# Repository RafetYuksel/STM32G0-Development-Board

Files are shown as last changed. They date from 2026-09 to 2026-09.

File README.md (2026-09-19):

# STM32G0-Development-Board

A custom 4-layer development board based on the **STM32G0B1RET6** microcontroller, designed from schematic through PCB layout with a focus on practical hardware design, power management, USB, industrial communication interfaces, debugging, and PCB design practices.

---

## Overview

This project is a custom STM32G0 development board designed and developed from the ground up.

The board provides a general-purpose hardware platform for embedded development and includes USB connectivity, CAN, RS485, SWD debugging, UART, I2C and SPI interfaces.

The design process includes:

- System architecture
- Schematic design
- Component selection
- Power architecture
- PCB layout
- 4-layer PCB stack-up
- Ground-plane design
- USB differential-pair routing
- Communication interfaces
- Design Rule Check (DRC) 
- PCB manufacturing
- Hardware bring-up

---

## Key Features

| Feature | Description |
|---|---|
| MCU | STM32G0B1RET6 |
| PCB | 4-layer |
| USB | USB Type-C |
| Debug | SWD |
| CAN | FDCAN1 |
| RS485 | MAX3485 |
| UART | USART2 |
| I2C | Header |
| SPI | Header |
| Logic Supply | 3.3 V |
| USB Supply | 5 V |
| External Input | Supported |
| Protection | Input protection and USB ESD protection |
| Status | LEDs and user button |

---

## System Architecture

```text
                         ┌─────────────────────┐
                         │      USB Type-C     │
                         │    Power + USB      │
                         └──────────┬──────────┘
                                    │
                                    ▼
                         ┌─────────────────────┐
                         │   Power Management  │
                         │ Protection + DC/DC  │
                         └──────────┬──────────┘
                                    │      
                              5 V / 3.3 V
                                    │
                                    ▼
                         ┌─────────────────────┐
                         │    STM32G0B1RET6    │
                         │        MCU          │
                         └──────┬──┬──┬──┬────┘
                                │  │  │  │
                    ┌───────────┘  │  │  └───────────┐
                    │              │  │              │
                    ▼              ▼  ▼              ▼
                  USB             CAN RS485       SWD
                    │              │  │              │
                    ▼              ▼  ▼              ▼
                USB ESD         Transceivers     Debugger
                Protection

```
---

## Hardware Design

### MCU
* **Main Controller:** STM32G0B1RET6
* Provides processing, communication, and peripheral interfaces required by the board.
* Includes local decoupling capacitors and dedicated filtering for the MCU supply.
* MCU analog supply is additionally filtered from the main 3.3 V rail.

### Power Management
Supports USB and external power input.

**Power Architecture:**
USB-C / External Input
          │
          ▼
   Input Protection
          │
          ▼
       SYS_5V
          │
          ▼
        3.3 V
          │
          ▼
    STM32G0 + Logic

### USB
USB connectivity is provided through a USB Type-C connector with data lines routed as a differential pair on the PCB.
* USB Type-C connector
* USB VBUS & CC resistors
* USB ESD protection
* USB differential data lines

### CAN
Connected to the STM32G0 FDCAN peripheral. The termination network allows configuration based on its position in the CAN bus.
* CANH / CANL lines
* CAN transceiver & connector
* Selectable termination (Jumper-selectable)

### RS485
Uses an MAX3485 transceiver for RS485 communication.
* MCU UART connection
* Driver Enable control
* RS485 A/B lines
* RS485 termination (Jumper-selectable)
* External connector

### Debug Interface
Provides Serial Wire Debug (SWD) interface for programming and debugging via an external ST-LINK debugger. Access provided to:
* SWDIO & SWCLK
* 3.3 V & GND
* MCU reset

### Peripheral Interfaces
Exposes several MCU peripherals through external headers to act as a general-purpose embedded development platform:
* UART, I2C, SPI
* CAN, RS485
* GPIO

---

## PCB Design

### Stack-up (4-Layer)
| Layer | Name | Description |
| :--- | :--- | :--- |
| **Layer 1** | TOP | Components and signal routing |
| **Layer 2** | GND | Ground plane |
| **Layer 3** | INNER SIGNAL | Signal routing |
| **Layer 4** | BOTTOM | Signal routing |

* A dedicated internal ground layer (Layer 2) provides continuous ground coverage, low-impedance return paths, and improved return-current dynamics.
* Ground stitching vias are placed throughout to enhance connections between ground regions.

### PCB Layout Considerations
* MCU decoupling capacitor placement & short USB signal paths
* Power-rail routing & ground-plane continuity
* USB differential-pair routing
* Communication-interface routing
* Ground stitching & signal/power routing
* **DRC:** Completed using CircuitMaker Design Rule Check.

---

## Design Decisions

* **4-Layer PCB:** Selected to provide additional routing space, low-impedance return paths, and a dedicated internal ground plane.
* **Ground Plane:** Dedicated GND plane on Layer 2 with stitching vias added where appropriate to improve continuity between PCB regions.
* **USB Differential Pair:** D+ and D− signals routed as a differential pair in a compact layout around the connector, ESD protection, and MCU.
* **Selectable CAN Termination:** Jumper-selectable termination resistor allows use at either end of a CAN bus or without local termination.
* **Selectable RS485 Termination:** Jumper-selectable termination network to enable or disable based on position in the network.

---

## Manufacturing & Status

### Manufacturing Workflow
Schematic -> PCB Layout -> DRC -> PCB Manufacturing -> Bare PCB Received -> Component Assembly -> Hardware Bring-up -> Firmware Validation

### Project Status
* **Hardware Design:** Complete
* **PCB Manufacturing:** Complete
* **Bare PCB:** Received
* **Component Assembly:** Pending
* **Hardware Bring-up:** Pending
* **Firmware Validation:** Pending

---

## Firmware & Bring-up Plan

Firmware development will be performed using **STM32CubeIDE**.

Planned firmware validation includes:
* GPIO, UART, USB, CAN, RS485
* ADC, Timers, PWM
* SWD debugging

### Hardware Bring-up Sequence
1. Visual inspection
2. Power-input verification
3. 5 V rail verification
4. 3.3 V rail verification
5. MCU supply verification
6. SWD connection
7. MCU programming
8. Peripheral tests (GPIO -> UART -> USB -> CAN -> RS485)

### Validation Matrix
| Function / Test | Status |
| :--- | :--- |
| Visual inspection | Pending |
| Power input | Pending |
| SYS_5V | Pending |
| 3.3 V | Pending |
| MCU power | Pending |
| SWD | Pending |
| GPIO | Pending |
| UART | Pending |
| USB | Pending |
| CAN | Pending |
| RS485 | Pending |

---

## Repository Structure

```text
STM32G0-Development-Board/
├── Hardware/
│   ├── Schematic/
│   ├── PCB/
│   ├── BOM/
│   └── 3D/
├── Firmware/
├── Documentation/
├── Images/
└── README.md

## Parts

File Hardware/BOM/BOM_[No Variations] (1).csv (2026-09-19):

Comment | Description | Designator | Footprint | LibRef | Quantity
C&K Components KSC421G70SHLFS | Switch Tactile N.O. SPST Round Button Gull Wing 0.05A 32VDC 1VA 300000Cycle 2.12N SMD T/R | BTN1 | PCBComponent_1 | CMP-7597bcf2a0aaaa50-3 | 1
10uF | Cap Ceramic 10uF 25V X5R 10% SMD 0805 85°C Embossed T/R | C1, C4 | PCB-p4p2p2gnhi9hwenucyw6-1 | CMP-5c4a946cea47838d-4 | 2
22uF | 0805 22uF 25V X5R 20% multilayer ceramic capacitor | C2, C5 | CAPC2013X94X50ML20T25 | CMP-ef25233f913230e2-1 | 2
100nF | Ceramic capacitor SMD-0603 100nF 50V X7R# K +-10%, Samsung, RoHS | C3, C6, C7, C9, C10, C11 | Samsung CL10B104KB8NNNC-Footprint-1 | CMP-1af8d38ac64bc53f-24 | 6
1uF | 1uF Ceramic capacitor SMD-0603 1uF 50V X5R# K +-10%, Samsung, RoHS | C8 | CAPC1608X90X35LL15T15 | CMP-f7023f64287128c5-7 | 1
4.7uF | Multilayer Ceramic Capacitors MLCC - SMD/SMT 0805 4.7uF 35volts X5R 20% | C12 | CAPC2013X95X45LL15T25 | CMP-8267229-2 | 1
100nF | Capacitor; ECWF, Met Polypropylene Film Cap, Radial, 50V, 10uF, 5%, Blk ST | C13, C14 | RESC2013X50X30ML20T20 | CMP-e7d62c864ecd3811-3 | 2
Fairchild Semiconductor SS14 | DIODE SCHOTTKY 40V 1A SMA | D1 | SMB | CMP-814764-5 | 1
VIN TVS | Diode; 30.2 A (Max.); 13.30 V (Min.) @ 1 mA; 5 uA (Max.) @ 12 V; 100 A (Max.) | D2 | PCB-9qq8yczch7qbe6np1bha-1 | CMP-f10c38c5a08b2ecb-7 | 1
OR-ing Schottky | PMEG4010AESB - 40 V, 1 A low VF MEGA Schottky barrier rectifier | D3 | Nexperia PMEG4010AESBYL-Footprint-1 | CMP-63ffae44396ebc38-2 | 1
Kingbright APFA3010SEKJ3ZGKQBKC | 3.0MMX1.0MM Right Angle SMD Chip Led Lamp | D4 | PCB-xa6wagpttn61v02uvygv-1 | CMP-91425c46545c4e85-2 | 1
GREEN | 2.4 V Green LED 1608 (0603) SMD, Lite-On LTST-C190KGKT | DS1 | LTST-C190KGKT | CMP-e1642866a00b3ea3-15 | 1
Bourns MF-PSMF050X-2 | FUSE PTC RESETTABLE SMD 0805 | F1 | PCB-277780-1 | CMP-277780-4 | 1
BLM18AG601SN1D | Chip Ferrite Bead for General Use, 600 Ohm, 500 mA, -55 to 125 degC, 1.6 x 0.8 x 0.95 mm SMD, Tape and Reel | FB1 | MURA-BLM18-RF-H4-CHIP-2_V | CMP-14419471-5 | 1
Samtec FTSH-105-01-F-DV-K | Conn Unshrouded Header HDR 10 POS 1.27mm Solder ST SMD Automotive Tube | J1 | PCB-sbymt8py0jvp2ryn5bcq-1 | CMP-51de9854a3aa8e19-9 | 1
TYPE-C-31-M-12 | 250mA 1 16 Female Type-C SMD USB Connectors ROHS | J2 | HRO Electronics TYPE-C-31-M-12-Footprint-1 | CMP-a3766f9095887cb1-3 | 1
TE Connectivity 825433-6 | Conn Unshrouded Header HDR 6 POS 2.54mm Solder ST Thru-Hole - No Outline | J5 | PCB-2xrknp0frdgvb29ud8aa-1 | CMP-88ed4362af17572a-9 | 1
Harwin M50-3530242 | Prices include import duty and tax. BTB CONN, HEADER, 2POS, 1ROWS, 1.27MM | J6, J7 | PCB-kdbzezog7lgzeuckpa59-1 | CMP-8a7247a62d3655b5-1 | 2
Molex 0022284100 | 2.54mm (.100") Pitch KK® Header, Breakaway, Vertical, 10 Circuits, Tin (Sn) Plating, Mating Pin Length 6.09mm (.240") | J8 | HDR1X10 | CMP-4d308488f3b592f7-3 | 1
Samtec TSM-112-01-L-SV | "This surface mount .025” square post terminal strip features single | J9 | Samtec TSM-112-01-L-SV-Footprint-1 | CMP-86a14eaf92625966-1 | 1
Phoenix Contact 1729128 | SERVAL Bornera negra 2 vias | J_EXT | PCB-751788-1 | CMP-751788-39 | 1
Amphenol ICC / FCI 68000-103HLF | Conn Unshrouded Header HDR 3 POS 2.54mm Solder ST Top Entry Thru-Hole BergStik® Bulk | JP1, JP2 | Hdr_1x3_2.54mm | CMP-8ffa44933221503d-6 | 2
Coilcraft XAL5030-472MEC | Power inductor, shielded, 20% tol, SMT, RoHS, halogen f | L1, L2 | PCB-eh2uh0b1ckxc83nsi4qq-1 | CMP-6f03a7253721b0c4-1 | 2
P-MOSFET | Power MOSFET, -20 V, -1 A, P-Channel, 3-Pin SOT-23, Pb-Free, Tape and Reel | Q1 | ONSC-SOT-23-3-318-08_V | CMP-19304379-2 | 1
4.7k | Res Thick Film 0603 4.7K Ohm 1% 1/10W ±100ppm/°C Molded SMD Paper T/R | R1, R2 | Yageo RC0603FR-074K7L-Footprint-1 | CMP-e2bf28f8a65d3d78-15 | 2
Yageo RC0603FR-07120RL | Chip Resistor, 120 Ohm, +/- 1%, 100 mW, -55 to 155 degC, 0603 (1608 Metric), RoHS, Tape and Reel | R3, R12 | RESC1608X55X25LL10T15 | CMP-1900331-5 | 2
1k | YAGEO (PHYCOMP) RC0603FR-071KL RESISTOR, THICK FILM, 1K, 0.1W, 1% | R4 | R0603_A | CMP-1853278-34 | 1
330 | Res Thick Film 0603 330 Ohm 1% 0.1W(1/10W) ±100ppm/C Pad SMD T/R | R5, R6, R7 | RESC1608X55X30LL15T15 | CMP-1853593-9 | 3
10k | RES 10K OHM 1% 1/10W 0603 | R8 | RC0603FR-0710KL-Footprint-1 | CMP-c4650f0d5cc11ba2-40 | 1
100k | 100 kOhms ±1% 0.1W, 1/10W Chip Resistor 0603 (1608 Metric) Moisture Resistant Thick Film | R9 | YAGEO RC0603FR-07100KL-Footprint-1 | CMP-9abf51c576ad4578-32 | 1
10k | Thick Film Resistors - SMD 0402 47ohms 5% Tol | R10, R11 | Panasonic ERJ-2GEJ470X-Footprint-1 | CMP-3651607-3 | 2
Yageo RC0603FR-07 5K1L | Res Thick Film 1.6 x 0.8 mm 5.1K Ohm 1% 0.1W(1/10W) 100ppm/ C Molded SMD Paper T/R | R15, R16 | RESC1608X06N | CMP-cb9401c58a0b1453-1 | 2
TE Connectivity FSM2JSMA | Switch Tactile OFF (ON) SPST Round Button Gull Wing 0.05A 24VDC 1.57N SMD Loose | SW1 | PCB-ceqr8z8zluiv0xnbvd9i-1 | CMP-5bcd9002db93840a-9 | 1
TestPoint SMD | Test Point; Micro Mini; SMT | TP1, TP2, TP3, TP4, TP5, TP6, TP7, TP8 | Testpoint_With_Via | CMP-0dc8c4c22640d20f-23 | 8
Diodes Inc. AP63203WU-7 | AP63203 Series 3.3 V 2 A SMT Fixed Low IQ Synchronous Buck - TSOT-26 | U1, U2 | DIOD-DMMT5401-SOT-23-6_N | CMP-0ef5c227cacdd132-7 | 2
STMicroelectronics STM32G0B1RET6 | MCU 32-bit ARM Cortex M0+ RISC 512KB Flash 1.8V/2.5V/3.3V 64-Pin LQFP Tray | U3 | STM-LQFP64_N | CMP-0c25c3952bc2d3e2-3 | 1
USBLC6-2SC6 | USBLC6 Series 2 Line 6 V Uni / Bi-Directional ESD Protection - SOT-23-6 | U4 | SOT95P280X145-6N | CMP-756ebe39126caaa9-28 | 1
Texas Instruments (TI) SN65HVD230DR | 3.3 V CAN Transceiver with Standby Mode 8-SOIC -40 to 85 | U5 | SOIC8_1R27_4R9X6 | CMP-19361092-6 | 1
Maxim Integrated MAX3485EESA+ | MAX3485E Series 12 Mbps 3.6 V Half-Duplex SMT RS 485 Transceiver - SOIC-8 | U6 | PCB-ckpkxznd73w9x719u7e5-1 | CMP-5f72942638ab80b5-1 | 1

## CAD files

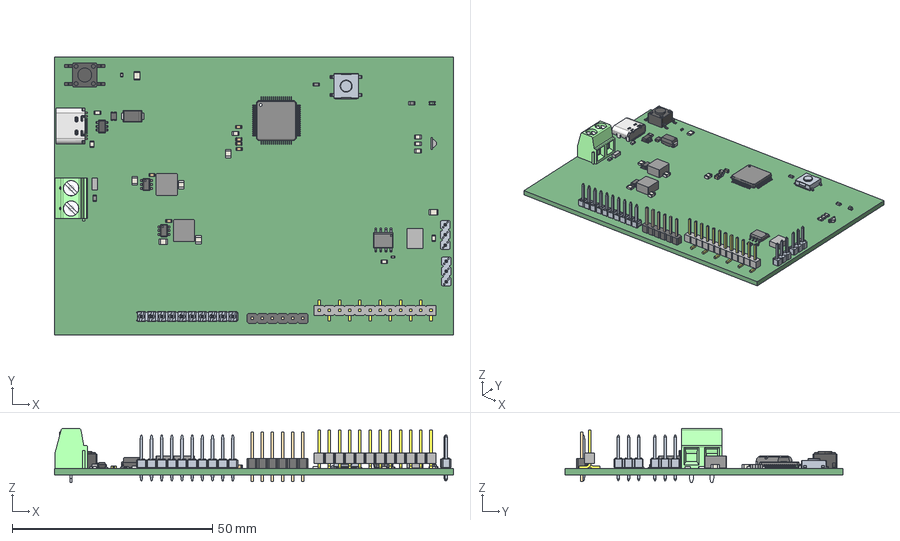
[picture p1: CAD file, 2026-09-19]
Hardware/3D/STEP_[No Variations] for STM32G0_DevBoard.CMPcbDoc.step
99.7 x 69.4 x 13.5 mm
Extruded x 60
CL10B104KB8NNNC x 6
SOIC-8
SOT23-6L
STM32G0B1RET6--3DModel-STEP-510211
User Library-ZXTC2045E6TA x 2
c-2-1437565-7-v-3d_RGB0
RC0603FR-0710KL
0603-RES
77310_Y16 x 6
mkdsn_1.5-2-5.08
T-1S6-16(-01-12-SV)
TSM-112-01-SV_body
HRO_TYPE-C-31-M-12 x 4
pcb
top
lead
lead -notch
emitter
DO214AC S1G-1
450_c-2506469-1-a-3d
Yageo Logo

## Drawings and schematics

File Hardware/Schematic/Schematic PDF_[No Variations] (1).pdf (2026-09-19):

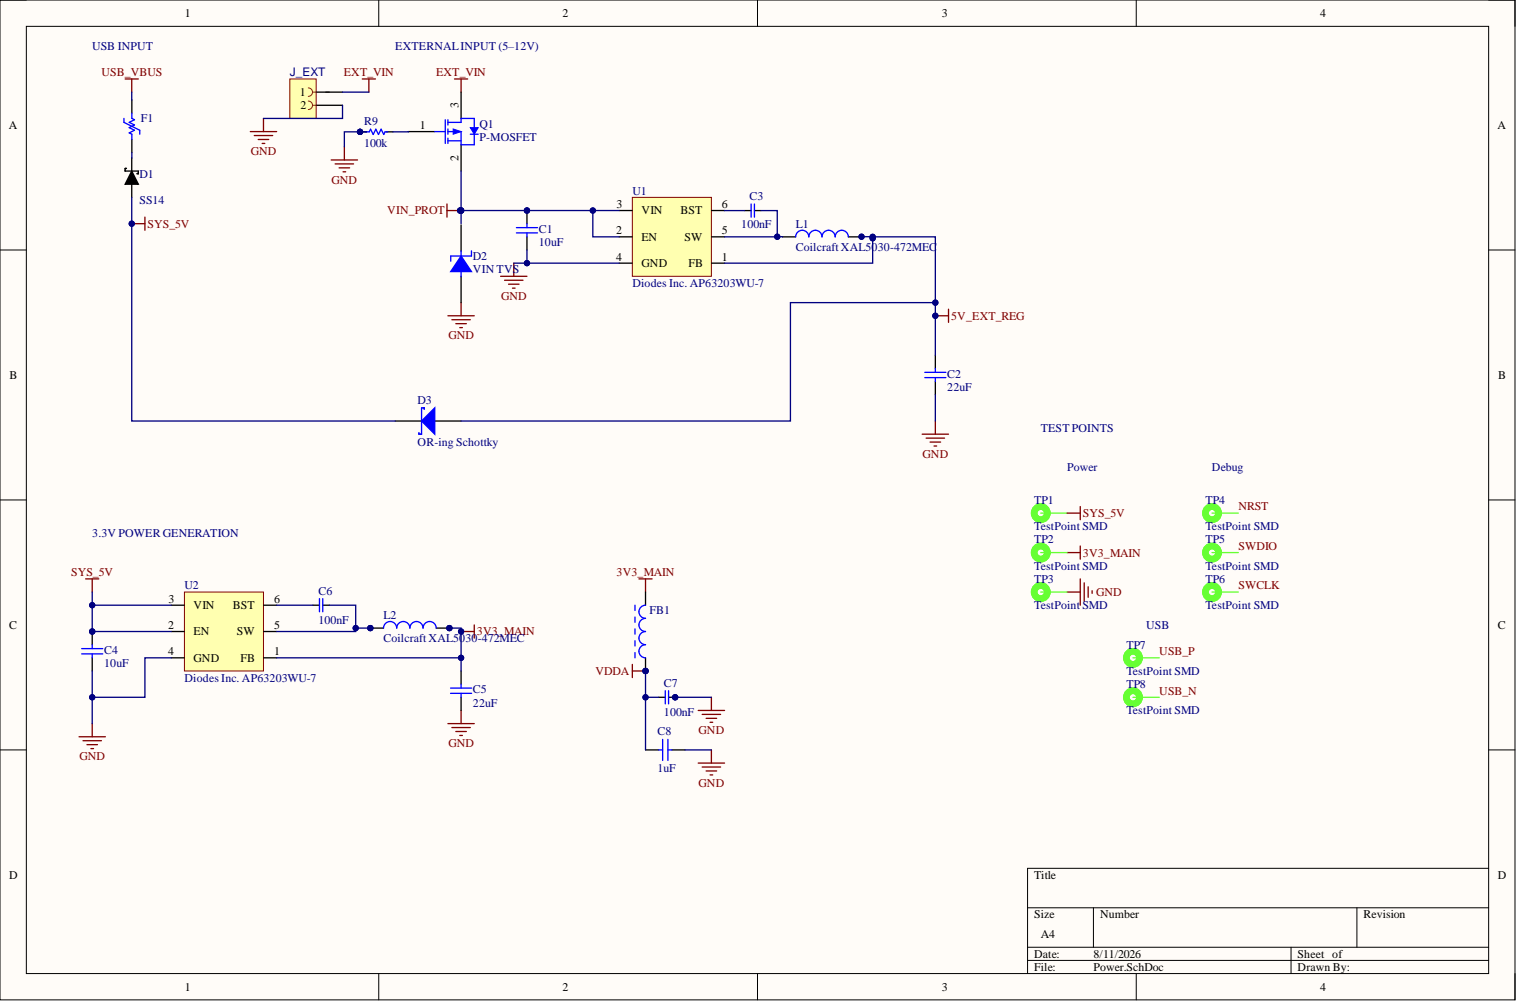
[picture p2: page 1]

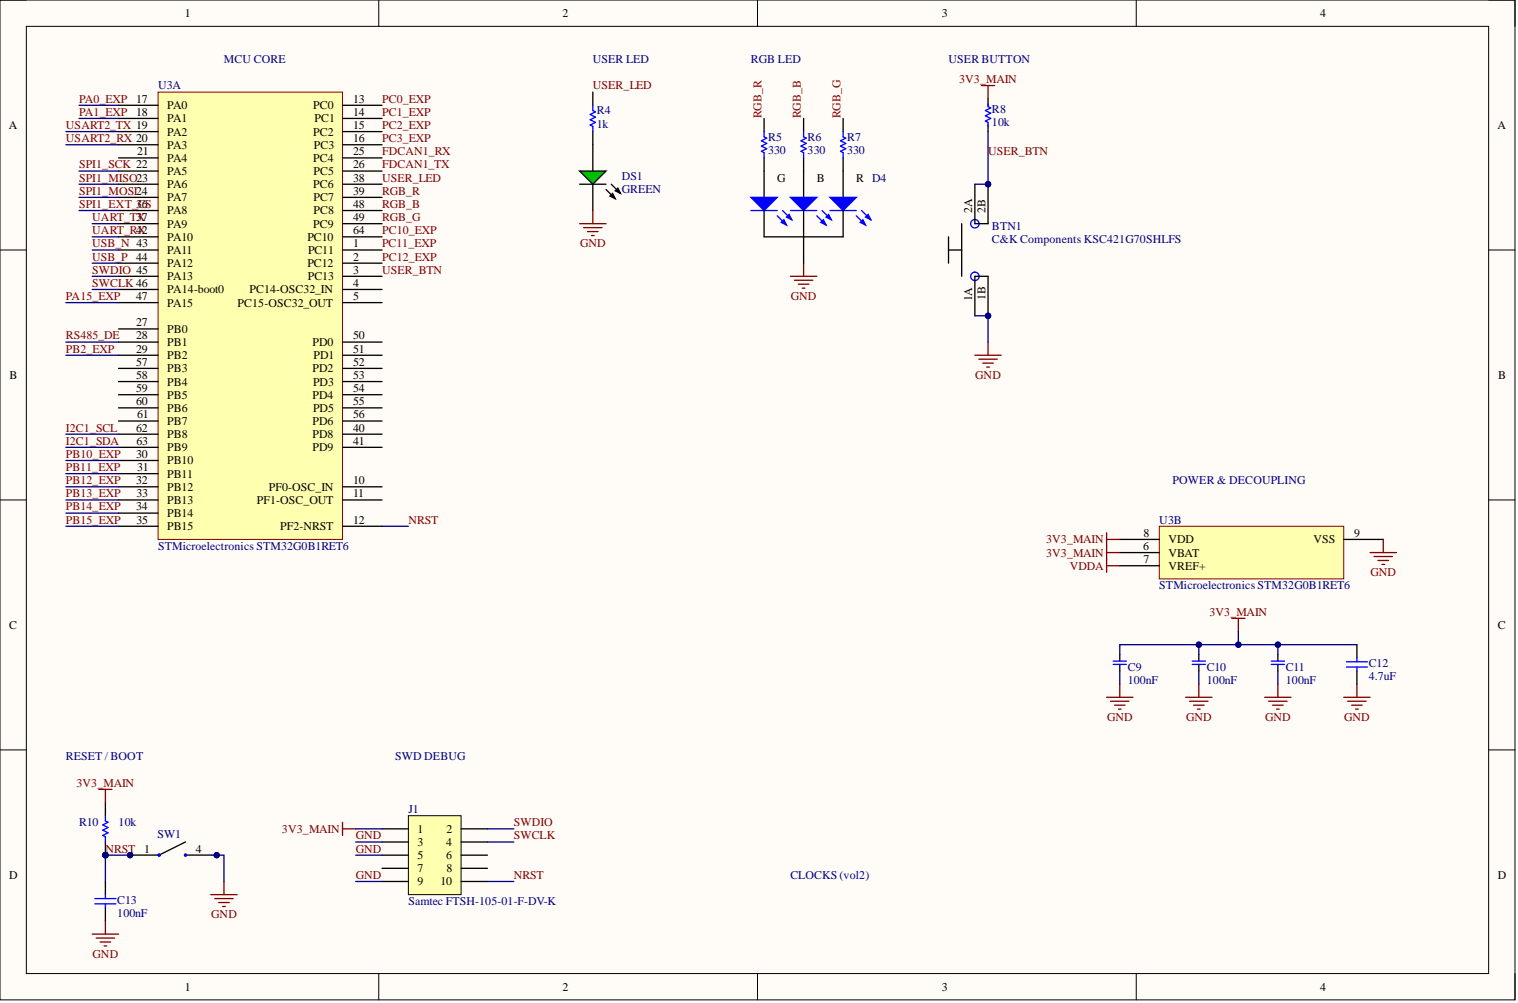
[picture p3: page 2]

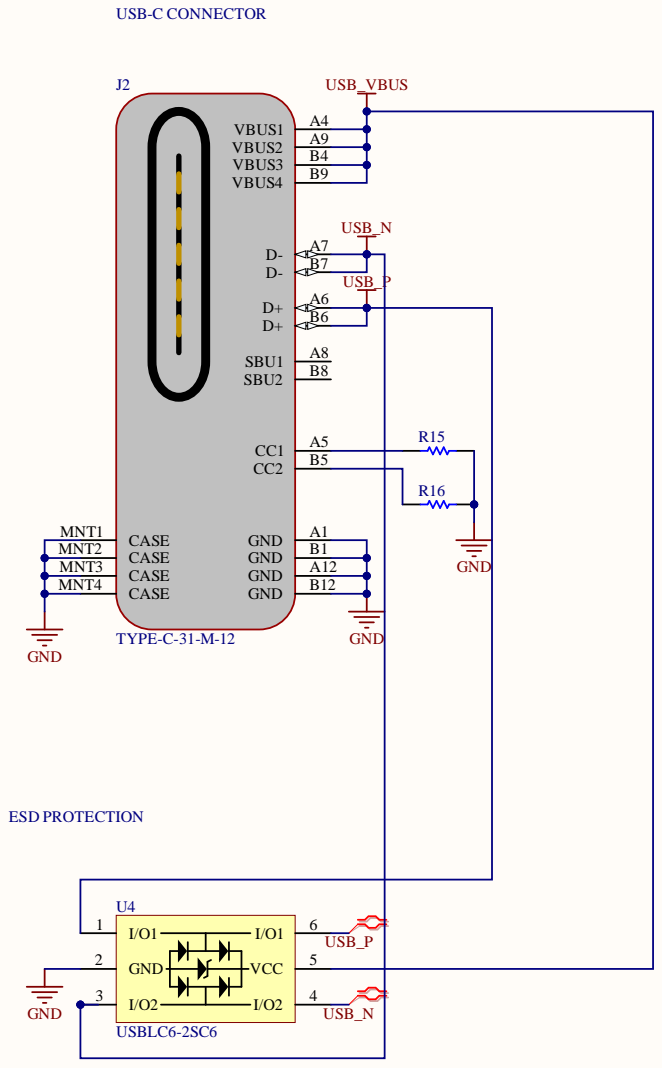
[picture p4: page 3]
Date:; Sheet of; File:; USB.SchDoc; Drawn By:; USB-C CONNECTOR; ESD PROTECTION; GND; A12 GND; CASE MNT1 CASE MNT2 CASE MNT3 CASE MNT4

I/O1 1
GND 2 | USB_P

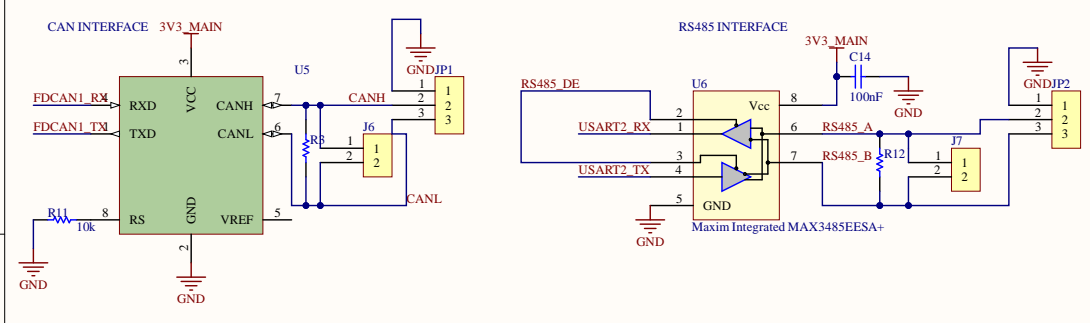
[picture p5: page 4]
VCC 3; GND 2; tegrated MA

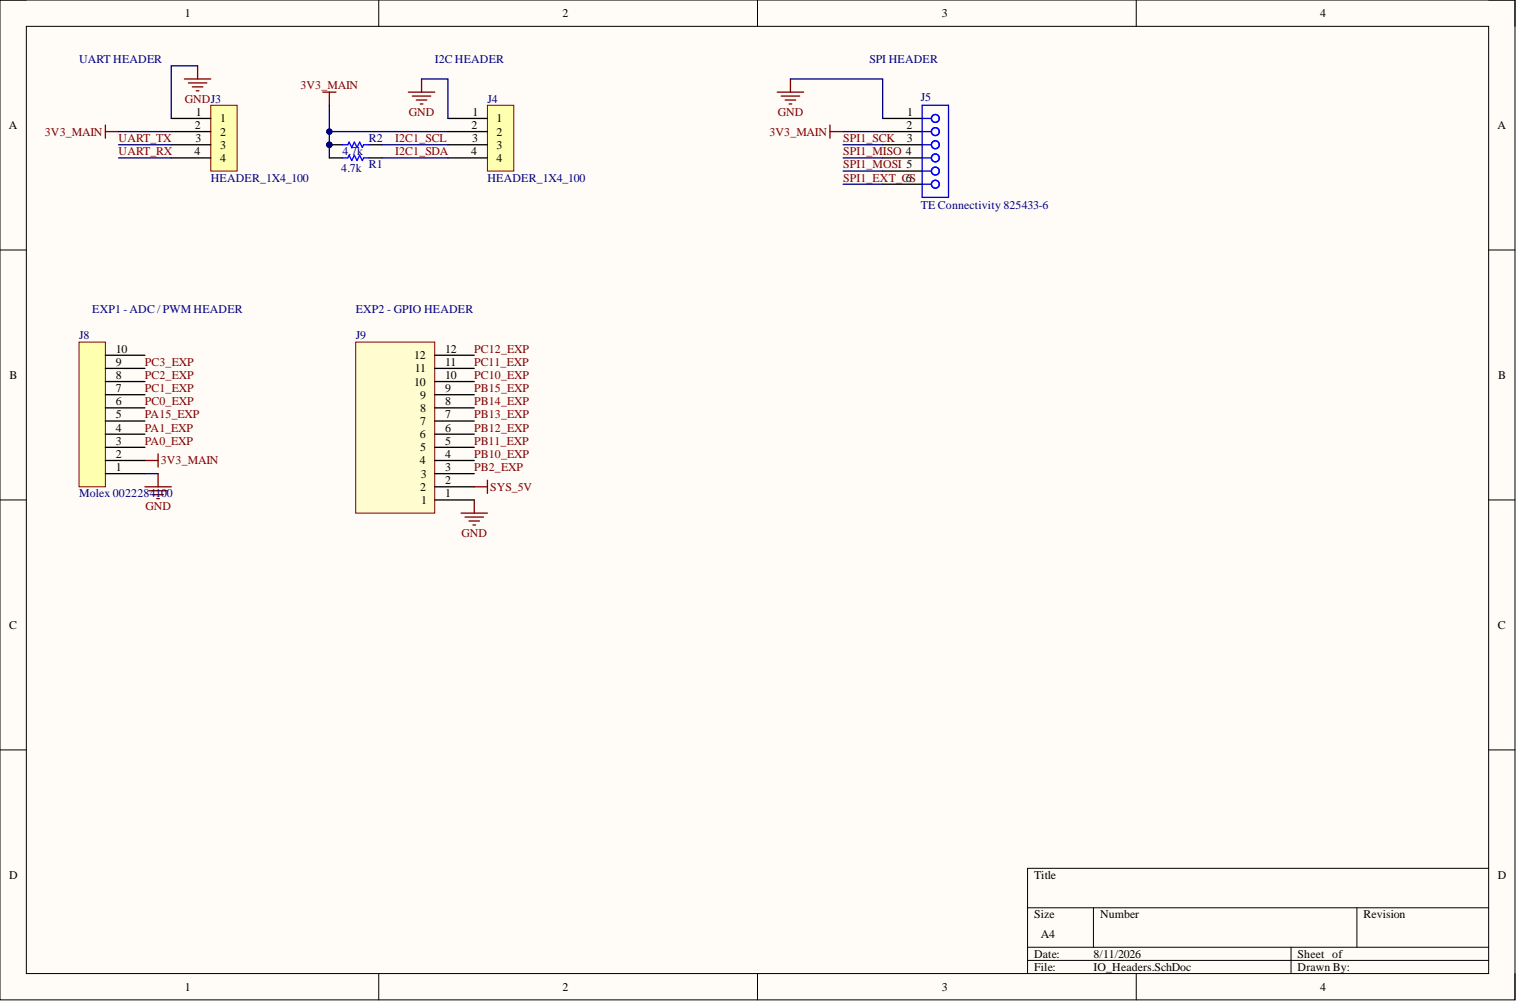
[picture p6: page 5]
Date:; Sheet of; File:; IO_Headers.SchDoc; Drawn By:; UART HEADER; I2C HEADER; TE Connectivity 825433-6; SPI HEADER; EXP1 - ADC / PWM HEADER; EXP2 - GPIO HEADER; Molex 0022284100
